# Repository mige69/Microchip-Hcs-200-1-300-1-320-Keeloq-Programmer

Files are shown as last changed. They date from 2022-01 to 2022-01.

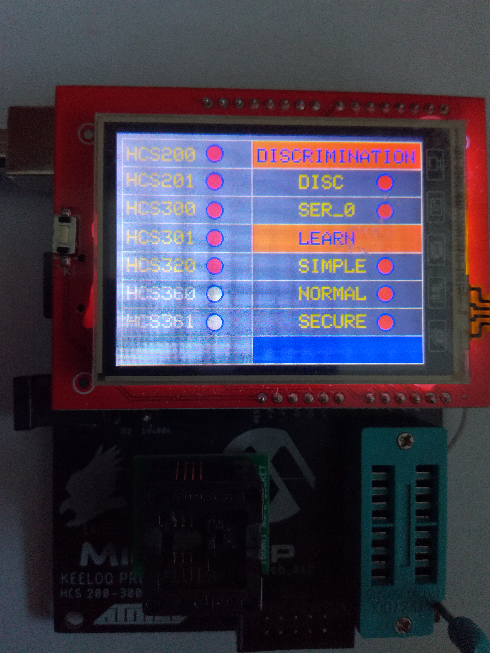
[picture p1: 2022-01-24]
hcs/IMG_20220124_160512.jpg

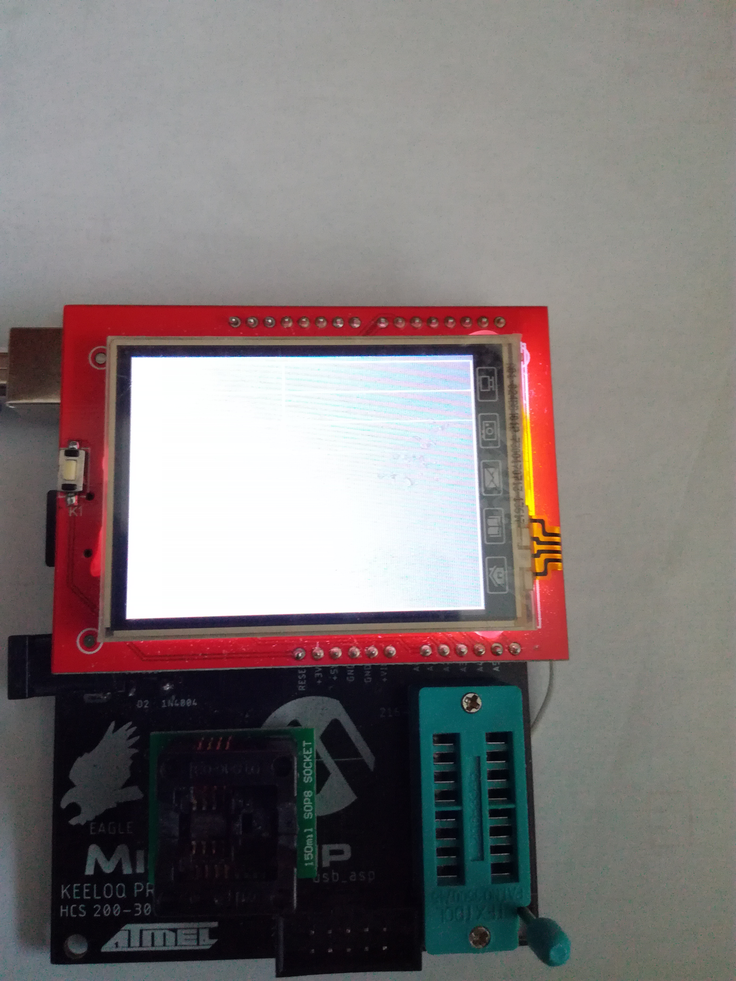
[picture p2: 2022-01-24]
hcs/IMG_20220124_160506.jpg

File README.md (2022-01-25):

# Microchip-Hcs-200-1-300-1-320-Keeloq-Programmer

programmer keeloq hcs200/1 hcs300/1 hcs320
verified program saves hcs content on sd card
atmega644 tqfp
shield tft 2.4 mcufriends touchscreen
Keeloq simple normal secure

adapter soic8
dip16 zif
test clip Sop8
programmer








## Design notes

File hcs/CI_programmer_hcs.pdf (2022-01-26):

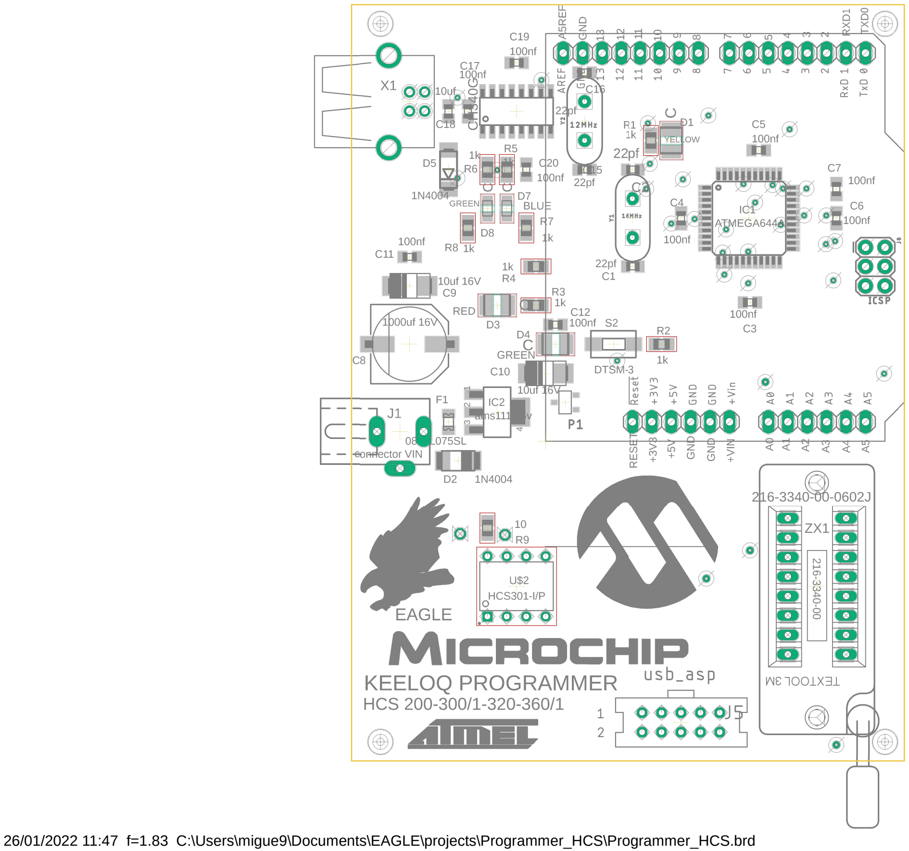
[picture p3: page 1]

26/01/2022 11:47 f=1.83 C:\Users\migue9\Documents\EAGLE\projects\Programmer_HCS\Programmer_HCS.brd

C8

connector VIN

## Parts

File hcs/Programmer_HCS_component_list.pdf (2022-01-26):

Partlist EAGLE/projects/Programmer_HCS/Programmer_HCS.sch

Part Value | Device | Package
Description
AVAILABILITY COMPANY-URL | CREATED-BY
CREATED-DATE DATASHEET-URL

DESCRIPTION
MANUFACTURER | MF | MP
MPN | OC_FARNELL OC_NEWARK PACKAGE | POPULARITY PRICE PROD_ID
PURCHASE-URL | SF_ID
VALUE
C1 | 22pf | C0805 | 0805
C2 | 22pf | C0805 | 0805
C3 | 100nf | C0805 | 0805
C4 | 100nf | C0805 | 0805
C5 | 100nf | C0805 | 0805

C6 | 100nf | C0805 | 0805
C7 | 100nf | C0805 | 0805
C8 | 1000uf 16V | C-PR-SMD-SV-G | SV-G | POLARIZED
ELECTROLYTIC/TANTALUM
C9 | 10uf 16V | CP6032 | 6032
C10 10uf 16V | CP6032 | 6032
C11 100nf | C0805 | 0805

C12 100nf | C0805 | 0805
C15 22pf | C0805 | 0805
C16 22pf | C0805 | 0805
C17 100nf | C0805 | 0805
C18 10uf | C0805 | 0805
C19 100nf | C0805 | 0805

C20 100nf | C0805 | 0805
D1 | YELLOW | WL-SMTW-150141AS73100-A 3528-2PIN | SMD Side
view mono-color round
http://www.we-online.de Christin Otto APR 2013
http://katalog.we-online.de/en/led/WL-SMTW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 mtw
Würth Elektronik eiSos GmbH
D2 | 1N4004 | DIODE-DO-214AC | DO-214AC | DIODE

25

D3 | RED | WL-SMTW-150141AS73100-A 3528-2PIN | SMD Side
view mono-color round
http://www.we-online.de Christin Otto APR 2013
http://katalog.we-online.de/en/led/WL-SMTW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 mtw
| | Würth Elektronik eiSos GmbH
D4 | GREEN | WL-SMTW-150141AS73100-A 3528-2PIN | SMD Side
view mono-color round
http://www.we-online.de Christin Otto APR 2013
http://katalog.we-online.de/en/led/WL-SMTW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 mtw
| | Würth Elektronik eiSos GmbH
D5 | 1N4004 | DIODE-DO214AA | DO214AA | DIODE

8

D7 | BLUE | WL-SMCW-150080RS75000-R 0805 | SMD
mono-color Chip LED
http://www.we-online.de Christin Otto APR 2013
http://katalog.we-online.de/en/led/WL-SMCW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
| | Würth Elektronik eiSos GmbH
D8 | GREEN | WL-SMCW-150080RS75000-R 0805 | SMD
mono-color Chip LED
http://www.we-online.de Christin Otto APR 2013
http://katalog.we-online.de/en/led/WL-SMCW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
| | Würth Elektronik eiSos GmbH
F1 | 0805L075SL | 0805L075SL | 0805L | Polyfuse
Resettable PTC

Littelfuse
0805L075SL | 2125905 | 88T7684
IC1 ATMEGA644A | ATMEGA644A | TQFP44 | 8-bit
Microcontroller with 64K Bytes In-System Programmable Flash
ATMEGA644PV-10AU 1455123 | 58M3748 | 5
IC2 ams1117 5v | LM1117 | SOT223

IC4 UNO | ARDUINO2009_PIN_10 | ARDUINO2009 | The
Arduino Duemilanove ("2009") is a microcontroller board based on the ATmega168 or ATmega328.
J1 | connector VIN | DCJ0303 | DCJ0303 | DC POWER
JACK
unknown | unknown | 20
J5 | usb_asp | SOCKET-10V | S10V | 10 pin
PCB Socket (3m 85xx/51xx)
J8 | ICSP | CONN_03X2FEMALE | 2X3 | Multi
connection point. Often used as Generic Header-pin footprint for 0.1 inch spaced/style header connections

CONN-11566
FEMALE 2x3
P1 | xc6206 3.3v | XC6206SOT-23 | XC6206_SOT-23 | XC6206P
, linear regulator.
R1 | 1k | R-EU_R0805 | R0805 | RESISTOR,
European symbol

R2 | 1k | R-EU_R0805 | R0805 | RESISTOR,
European symbol
R3 | 1k | R-EU_R0805 | R0805 | RESISTOR,
European symbol
R4 | 1k | R-EU_R0805 | R0805 | RESISTOR,
European symbol
R5 | 1k | R-EU_R0805 | R0805 | RESISTOR,
European symbol
R6 | 1k | R-EU_R0805 | R0805 | RESISTOR,
European symbol
R7 | 1k | R-EU_R0805 | R0805 | RESISTOR,
European symbol

R8 | 1k | R-EU_R0805 | R0805 | RESISTOR,
European symbol
R9 | 10 | R-EU_R0805 | R0805 | RESISTOR,
European symbol
S2 | DTSM-3 | DTSM-3 | DTSM-3
U$1 CH340G | CH340G | SOIC16
U$2 HCS301-I/P | HCS301-I/P | DIP787W46P254L927H533Q8 Check
prices
| Warning

IC CODE HOPPING ENCODER 8DIP Microchip HCS301-I/P
DIP-8 Microchip | None
https://pricing.snapeda.com/search/part/HCS301-I/P/?ref=eda
X1 | USB-B-H | USB-B-H | USB-B-H | USB
Connectors

Y1 | 16MHz | CRYSTAL-16MHZPTH-HC49US HC49US | 16MHz
Crystal

XTAL-08181
COM-00536 16MHz
Y2 | 12MHz | CRYSTAL-16MHZPTH-HC49US HC49US | 16MHz
Crystal

XTAL-08181
COM-00536 16MHz
ZX1 216-3340-00-0602J 216-3340-00-0602J | 216-3340-00-0602J | Zero
Insertion Force Socked
Warning

16 (2 x 8) Pos DIP, ZIF (ZIP), 0.3 (7.62mm) Row Spacing
Socket Gold Connector | 3M | 216-3340-00-0602J
None | None
https://pricing.snapeda.com/search/part/216-3340-00-0602J/?ref=eda

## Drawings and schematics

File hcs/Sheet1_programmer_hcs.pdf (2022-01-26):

A

A

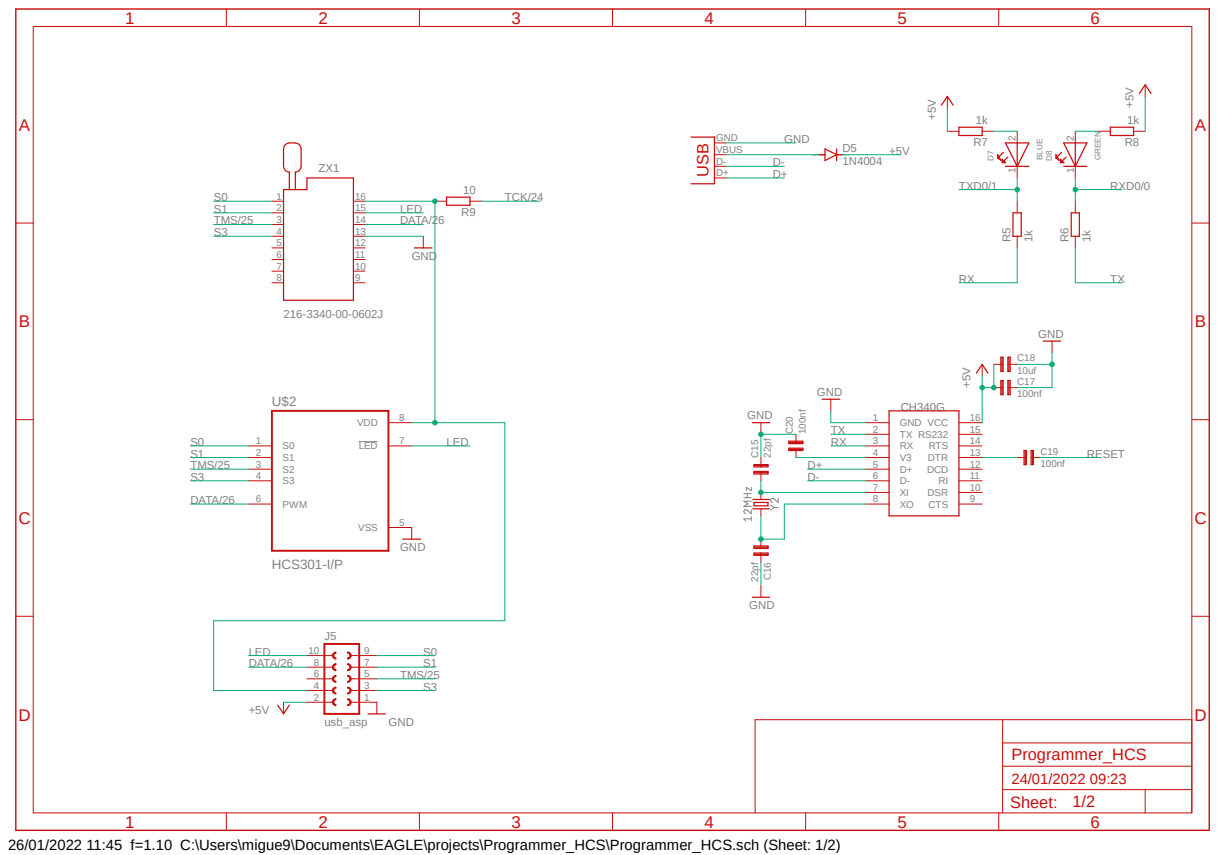
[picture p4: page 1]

26/01/2022 11:45 f=1.10 C:\Users\migue9\Documents\EAGLE\projects\Programmer_HCS\Programmer_HCS.sch (Sheet: 1/2)

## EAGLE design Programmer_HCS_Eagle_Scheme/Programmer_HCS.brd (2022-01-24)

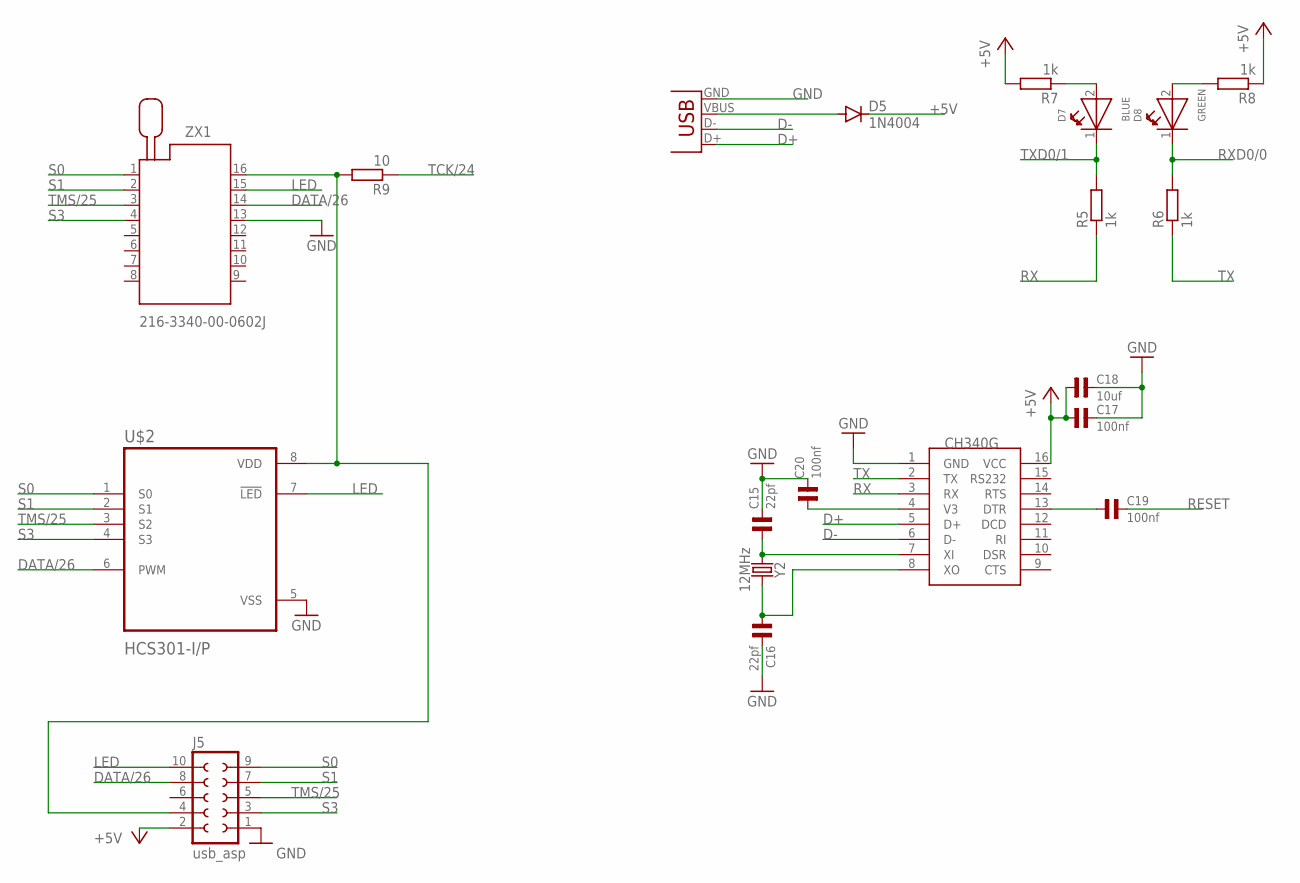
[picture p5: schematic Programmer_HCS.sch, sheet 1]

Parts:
C15, C16: 22pf; 0805
C17, C19, C20: 100nf; 0805
C18: 10uf; 0805
D5: 1N4004; DO214AA
D7: BLUE; 0805
D8: GREEN; 0805
J5: usb_asp; S10V
R5, R6, R7, R8: 1k; R0805
R9: 10; R0805
U$1: CH340G; SOIC16
U$2: HCS301-I/P; DIP787W46P254L927H533Q8
X1: USB-B-H
Y2: 12MHz; HC49US
ZX1: 216-3340-00-0602J

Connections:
+5V: C17.1, C18.1, D5.C, J5.2, R7.2, R8.1, U$1.16 (VCC); also elsewhere on the board
D+: U$1.5 (D+), X1.D+
D-: U$1.6 (D-), X1.D-
DATA/26: J5.8, U$2.6 (PWM), ZX1.14; also elsewhere on the board
GND: C15.2, C16.2, C17.2, C18.2, C20.2, J5.1, U$1.1 (GND), U$2.5 (VSS), X1.GND, ZX1.13; also elsewhere on the board
LED: J5.10, U$2.7 (!LED), ZX1.15
unnamed: C15.1, U$1.7 (XI), Y2.1
unnamed: C16.1, U$1.8 (XO), Y2.2
unnamed: D8.2 (A), R8.2
unnamed: D5.A, X1.VBUS
unnamed: C19.1, U$1.13 (DTR)
unnamed: D7.2 (A), R7.1
unnamed: C20.1, U$1.4 (V3)
unnamed: J5.4, R9.2, U$2.8 (VDD), ZX1.16
RESET: C19.2; also elsewhere on the board
RX: R5.1, U$1.3 (RX)
RXD0/0: D8.1 (K), R6.2; also elsewhere on the board
S0: J5.9, U$2.1 (S0), ZX1.1
S1: J5.7, U$2.2 (S1), ZX1.2
S3: J5.3, U$2.4 (S3), ZX1.4
TCK/24: R9.1; also elsewhere on the board
TMS/25: J5.5, U$2.3 (S2), ZX1.3; also elsewhere on the board
TX: R6.1, U$1.2 (TX)
TXD0/1: D7.1 (K), R5.2; also elsewhere on the board

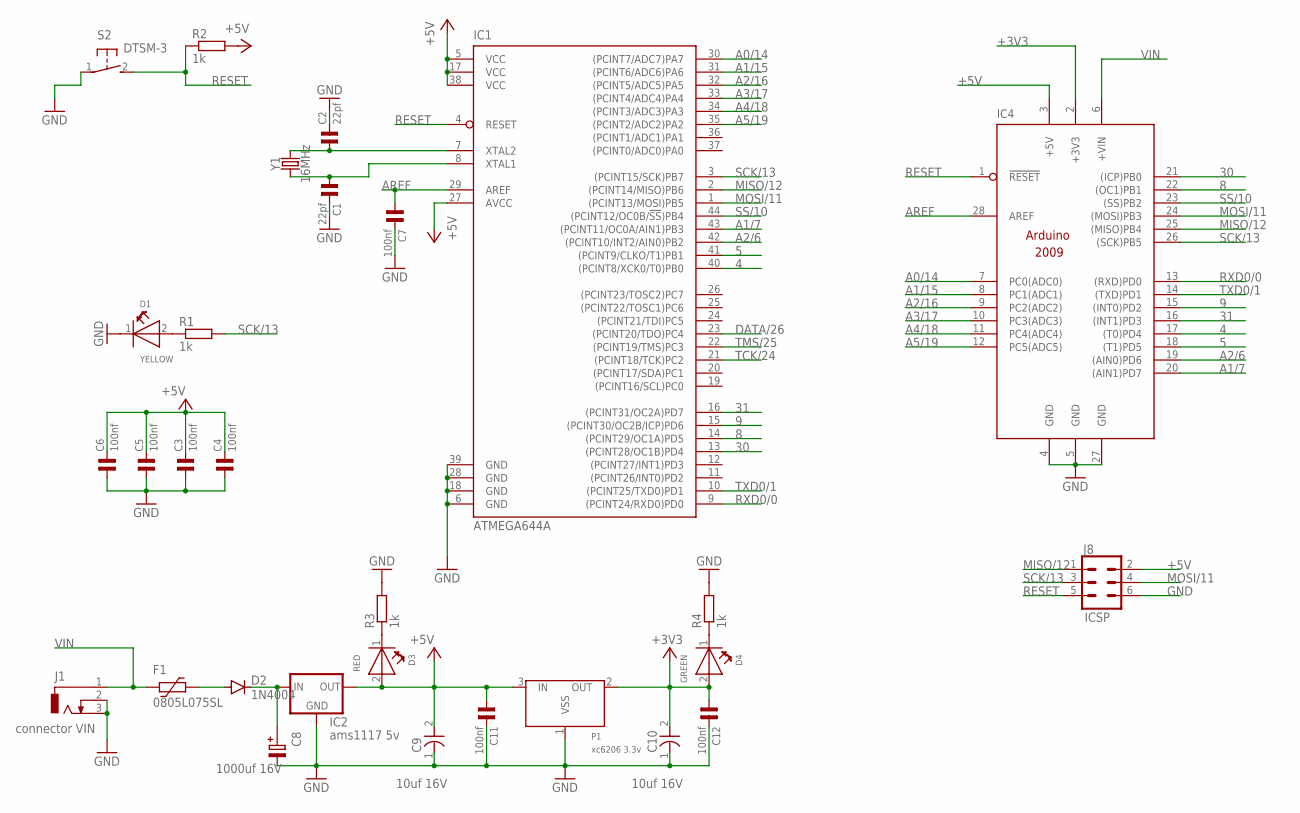
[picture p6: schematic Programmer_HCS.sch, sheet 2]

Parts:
C1, C2: 22pf; 0805
C3, C4, C5, C6, C7, C11, C12: 100nf; 0805
C8: 1000uf 16V; SV-G
C9, C10: 10uf 16V; 6032
D1: YELLOW; 3528-2PIN
D2: 1N4004; DO-214AC
D3: RED; 3528-2PIN
D4: GREEN; 3528-2PIN
F1: 0805L075SL; 0805L
IC1: ATMEGA644A; TQFP44
IC2: ams1117 5v; SOT223
IC4: UNO; ARDUINO2009
J1: connector VIN; DCJ0303
J8: ICSP; 2X3
P1: xc6206 3.3v; XC6206_SOT-23
R1, R2, R3, R4: 1k; R0805
S2: DTSM-3
Y1: 16MHz; HC49US

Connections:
4: IC1.40 ((PCINT8/XCK0/T0)PB0), IC4.17 ((T0)PD4)
5: IC1.41 ((PCINT9/CLKO/T1)PB1), IC4.18 ((T1)PD5)
8: IC1.14 ((PCINT29/OC1A)PD5), IC4.22 ((OC1)PB1)
9: IC1.15 ((PCINT30/OC2B/ICP)PD6), IC4.15 ((INT0)PD2)
30: IC1.13 ((PCINT28/OC1B)PD4), IC4.21 ((ICP)PB0)
31: IC1.16 ((PCINT31/OC2A)PD7), IC4.16 ((INT1)PD3)
+3V3: C10.2 (+), C12.1, D4.2 (A), IC4.2 (+3V3), P1.2 (OUT)
+5V: C3.2, C4.2, C5.2, C6.2, C9.2 (+), C11.1, D3.2 (A), IC1.5 (VCC), IC1.17 (VCC), IC1.27 (AVCC), IC1.38 (VCC), IC2.2 (OUT), IC4.3 (+5V), J8.2, P1.3 (IN), R2.2; also elsewhere on the board
A0/14: IC1.30 ((PCINT7/ADC7)PA7), IC4.7 (PC0(ADC0))
A1/7: IC1.43 ((PCINT11/OC0A/AIN1)PB3), IC4.20 ((AIN1)PD7)
A1/15: IC1.31 ((PCINT6/ADC6)PA6), IC4.8 (PC1(ADC1))
A2/6: IC1.42 ((PCINT10/INT2/AIN0)PB2), IC4.19 ((AIN0)PD6)
A2/16: IC1.32 ((PCINT5/ADC5)PA5), IC4.9 (PC2(ADC2))
A3/17: IC1.33 ((PCINT4/ADC4)PA4), IC4.10 (PC3(ADC3))
A4/18: IC1.34 ((PCINT3/ADC3)PA3), IC4.11 (PC4(ADC4))
A5/19: IC1.35 ((PCINT2/ADC2)PA2), IC4.12 (PC5(ADC5))
AREF: C7.1, IC1.29 (AREF), IC4.28 (AREF)
DATA/26: IC1.23 ((PCINT20/TDO)PC4); also elsewhere on the board
GND: C1.2, C2.2, C3.1, C4.1, C5.1, C6.1, C7.2, C8.-, C9.1 (-), C10.1 (-), C11.2, C12.2, D1.1 (K), IC1.6 (GND), IC1.18 (GND), IC1.28 (GND), IC1.39 (GND), IC2.1 (GND), IC4.4 (GND), IC4.5 (GND), IC4.27 (GND), J1.2, J1.3, J8.6, P1.1 (VSS), R3.2, R4.2, S2.1; also elsewhere on the board
MISO/12: IC1.2 ((PCINT14/MISO)PB6), IC4.25 ((MISO)PB4), J8.1
MOSI/11: IC1.1 ((PCINT13/MOSI)PB5), IC4.24 ((MOSI)PB3), J8.4
unnamed: C2.1, IC1.7 (XTAL2), Y1.2
unnamed: C1.1, IC1.8 (XTAL1), Y1.1
unnamed: D1.2 (A), R1.1
unnamed: C8.+, D2.C, IC2.3 (IN)
unnamed: D3.1 (K), R3.1
unnamed: D2.A, F1.1
unnamed: D4.1 (K), R4.1
RESET: IC1.4 (RESET), IC4.1 (!RESET), J8.5, R2.1, S2.2; also elsewhere on the board
RXD0/0: IC1.9 ((PCINT24/RXD0)PD0), IC4.13 ((RXD)PD0); also elsewhere on the board
SCK/13: IC1.3 ((PCINT15/SCK)PB7), IC4.26 ((SCK)PB5), J8.3, R1.2
SS/10: IC1.44 ((PCINT12/OC0B/!SS!)PB4), IC4.23 ((SS)PB2)
TCK/24: IC1.21 ((PCINT18/TCK)PC2); also elsewhere on the board
TMS/25: IC1.22 ((PCINT19/TMS)PC3); also elsewhere on the board
TXD0/1: IC1.10 ((PCINT25/TXD0)PD1), IC4.14 ((TXD)PD1); also elsewhere on the board
VIN: F1.2, IC4.6 (+VIN), J1.1

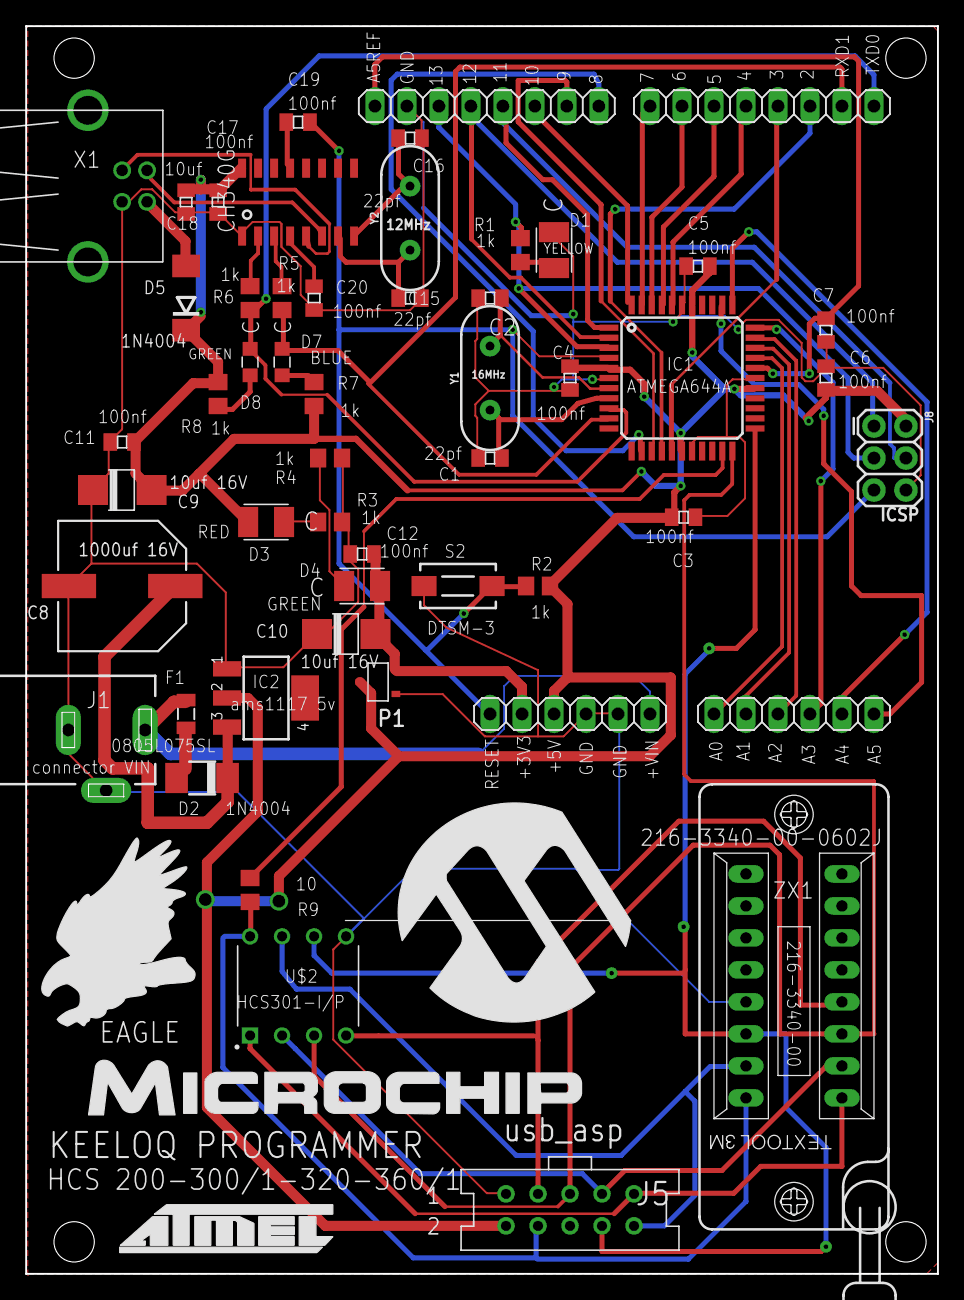
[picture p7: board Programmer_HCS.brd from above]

Board: 2 copper layers, 72.4 x 99.1 mm, 49 parts (0 on the bottom side), 52 nets.

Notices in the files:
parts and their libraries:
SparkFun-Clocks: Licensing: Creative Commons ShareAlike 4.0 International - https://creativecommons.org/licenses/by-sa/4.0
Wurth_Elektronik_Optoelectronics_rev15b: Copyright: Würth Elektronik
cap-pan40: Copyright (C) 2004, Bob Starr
